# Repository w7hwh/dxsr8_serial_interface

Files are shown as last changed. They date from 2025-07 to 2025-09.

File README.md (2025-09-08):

# DX-SR8 Serial Interface

## Introduction

Since I have a DX-SR8 and a few Raspberry Pi Picos sitting around I decided to try building an interface based on a Raspberry Pi Pico 2. If nothing else the project will force me to become more familiar with MicroPython.

Back in 2013 AJ9BM did an analysis of the communication between the DX-SR8's chassis and its front panel. He found out a great deal about the protocol and built working prototypes but he eventually abandoned the project. More about his work is in [aj9bm.md](./aj9bm.md).
 
The micropython didn't work so well for me so I've switched to programming in C to run under freeRTOS. This was picked because of the same reason many things are decided, I have experience with both C and freeRTOS. :^) Initially I'm using a "Blue Pill" board with a cpu labeled STM32F103CBT6 . The ST-INFO utility says it has 256k flash and 64k of ram instead of the lower amounts that chip is supposed to have. 

---

## Planned stages are:

- [x] Micropython firmware to continue analyzing the protocol using a breadboarded RPi Pico 2. Essentially use the Pico as a double channel usb-serial adapter with some analysis/decoding capability. This includes converting the original python2 to python3.

- [ ] Firmware to actually control the radio. Currently planned to be in C running under freeRTOS.

- [ ] Design a board.

- [ ] Add capability to send CAT commands to control the rig.

- [ ] Add capability to send/receive audio?

---

## Contents:

- aj9bm_code/ -- The original python analysis code AJ9BM wrote back in 2013.
- board/ -- Board design files
- documentation/ -- Documenting the protocol between radio and head.
- firmware_c/ -- My code to run in C on a STM32 cpu. (currently a STM32F103 based 'Blue Pill' board.)
- firmware_python/ -- My code to run in MicroPython on a Raspberry Pi Pico 2. This has been abandoned in favor of the C version.
- images/ -- Images

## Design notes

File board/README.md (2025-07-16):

# DXSR8 Serial Interface Design Files

## GPIO Usage

- GP0  
- GP1  
- GP2  
- GP3  
- GP4	UART1-TX serial send to chassis
- GP5	UART1-RX serial receive from head
- GP6  
- GP7  
- GP8  
- GP9  
- GP10  
- GP11  
- GP12	UART0-TX serial send to head
- GP13	UART0-RX serial receive from chassis
- GP14  
- GP15  
- GP16	I2C0-SDA for SH1106 based display
- GP17	I2C0-SCL for SH1106 based display
- GP18  
- GP19  
- GP20  
- GP21  
- GP22  GP22-RELAY-CTL
- GP23  (wireless module) OP wireless power on signal
- GP24  (wireless module) OP/IP SPI data/IRQ
- GP25  (wireless module) OP SPI CS, when high also enable GP29 to read VSYS
- GP26	ADC0 monitor power from chassis
- GP27  ADC1 monitor power from USB
- GP28  
- GP29  (wireless module) OP/IP SPI CLK/ADC3 mode read VSYS/3
- WL-GPOI0  (wireless module) OP to LED
- WL-GPOI1  (wireless module) OP controls SMPS power save
- WL-GPOI2  (wireless module) IP high if VBUS present

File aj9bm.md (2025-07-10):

# AJ9BM's DX-SR8 Serial Interface

Back in 2013 AJ9BM did an analysis of the communication between the DX-SR8's chassis and its front panel. He found out a great deal about the protocol and built working prototypes but he eventually abandoned the project.
 
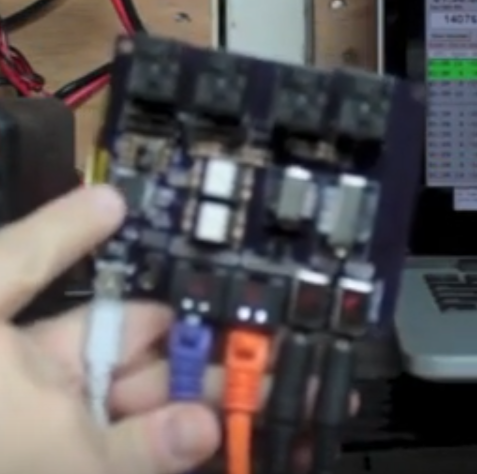
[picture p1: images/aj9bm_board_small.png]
aj9bm's board


Before he did he released the python analysis code that's in my /aj9bm_code directory [on Github](https://github.com/jbm9/dxsr8_serial).

He also posted three videos about the project on YouTube. Videos [showing the analysis code running](https://www.youtube.com/watch?v=cRo2k7FbKFA), [a prototype board controlling the rig](https://www.youtube.com/watch?v=0eBNIf6Rozc), and [one of a more finished prototype board controlling the rig](https://www.youtube.com/watch?v=aqtLbdCvwj8).

Unfortunately at that point he abandoned the project and never released the board design or the final code.

He added this to the captions on his videos:

> "UPDATE: I did not produce these for sale, and don't anticipate doing so.  There are enough kludges involved in getting this going that it's not worth sharing the project to other people, and (to be blunt) I would strongly recommend simply buying a better rig if you want to do computer control.  This is a great cheap 100W radio, but it's fairly dead-end in terms of third party support.  It doesn't even work properly with the autotuner you see in the video, for whatever reason."

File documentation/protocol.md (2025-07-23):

# DX-SR8 Head/Chassis Protocol

TODO:

- add examples and explainations for head to chassis part.

- document the chassis to head part.

---

## Introduction

The DXSR8's control head is connected to the chassis by a standard ethernet type cable with RJ45 connectors. It's not ethernet but it uses the same cable.

They communicate via two TTL level (5v) serial lines at 38400 8N1. They should not be directly connected to a 3.3v processor.

Most of the protocol was figured out by [AJ9BM](../aj9bm.md) back in 2013. He didn't produce documentation but it's in the python analysis code he released.

---

## Packets sent at powerup

b'AL~READY\r\n'

b'SWDA0000000081718AA1800100\r\n'

b'SWDV81728AA10100\r\n'

---

## Packets sent head to chassis

### AL~READY

b'AL~READY\r\n'

### SWDV

Contains rit, ifshift, squelch, and volume.

This is the most common packet because the values of these knobs jitter a little bit. These four are potentiometers and are read by ADCs (analog to digital converters). You get this even if you aren't touching the controls. They vary plus or minus one or two.

### SWDR

Contains the direction of rotation of the frequency dial

### SWDA

Related to the frequency dial? We get this packet when we spin the dial rapidly.

### SWDS

Contains the switches on the front panel excluding the power switch.
    
---

## Packets sent chassis to head

### AL~READY

b'AL~READY\r\n'

### LCSA

This contains bits controlling the LCD segments, LEDs, and display backlight. It seems to be the only thing the radio chassis transmits other than the initial ready message. It's sent continuously.

Details coming soon.

---

## Images of Display, Keys, and Head Schematic

Click for larger version.

Display

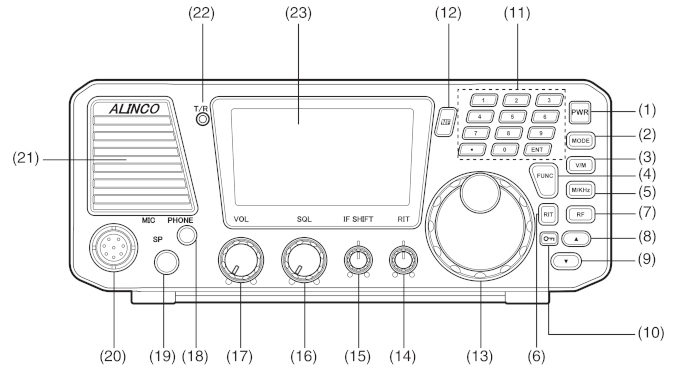
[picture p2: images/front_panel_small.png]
Front Panel


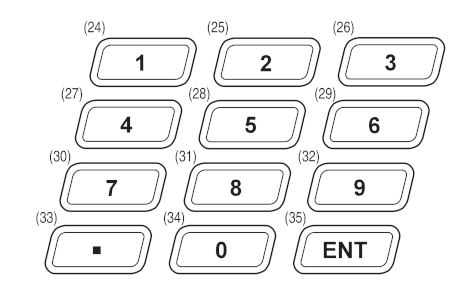
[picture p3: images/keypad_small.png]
Keypad


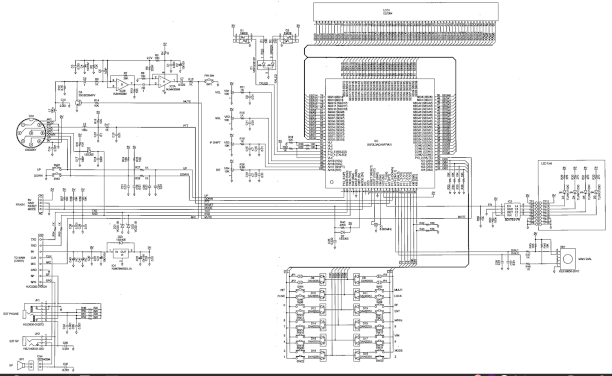
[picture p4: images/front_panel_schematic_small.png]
Front Panel Schematic


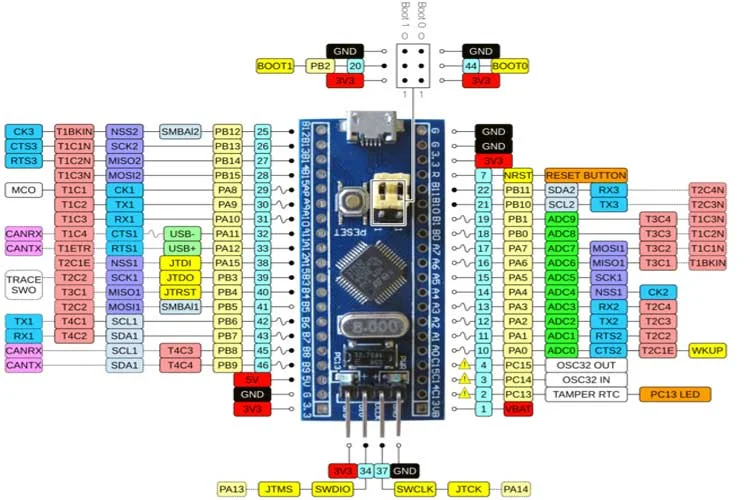
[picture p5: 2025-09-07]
documentation/STM32F103C8T6-Blue-Pill-pinout-diagram.webp

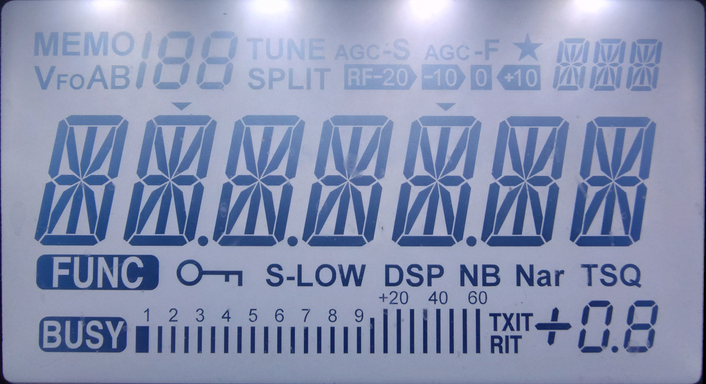
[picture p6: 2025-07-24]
images/display_all_segments_on.jpg

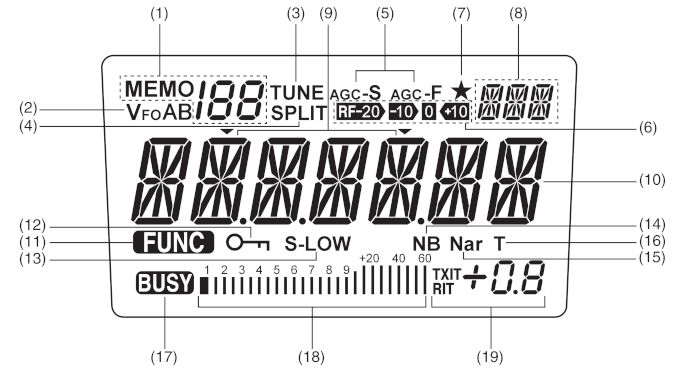
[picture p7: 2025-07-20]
images/display_small.png

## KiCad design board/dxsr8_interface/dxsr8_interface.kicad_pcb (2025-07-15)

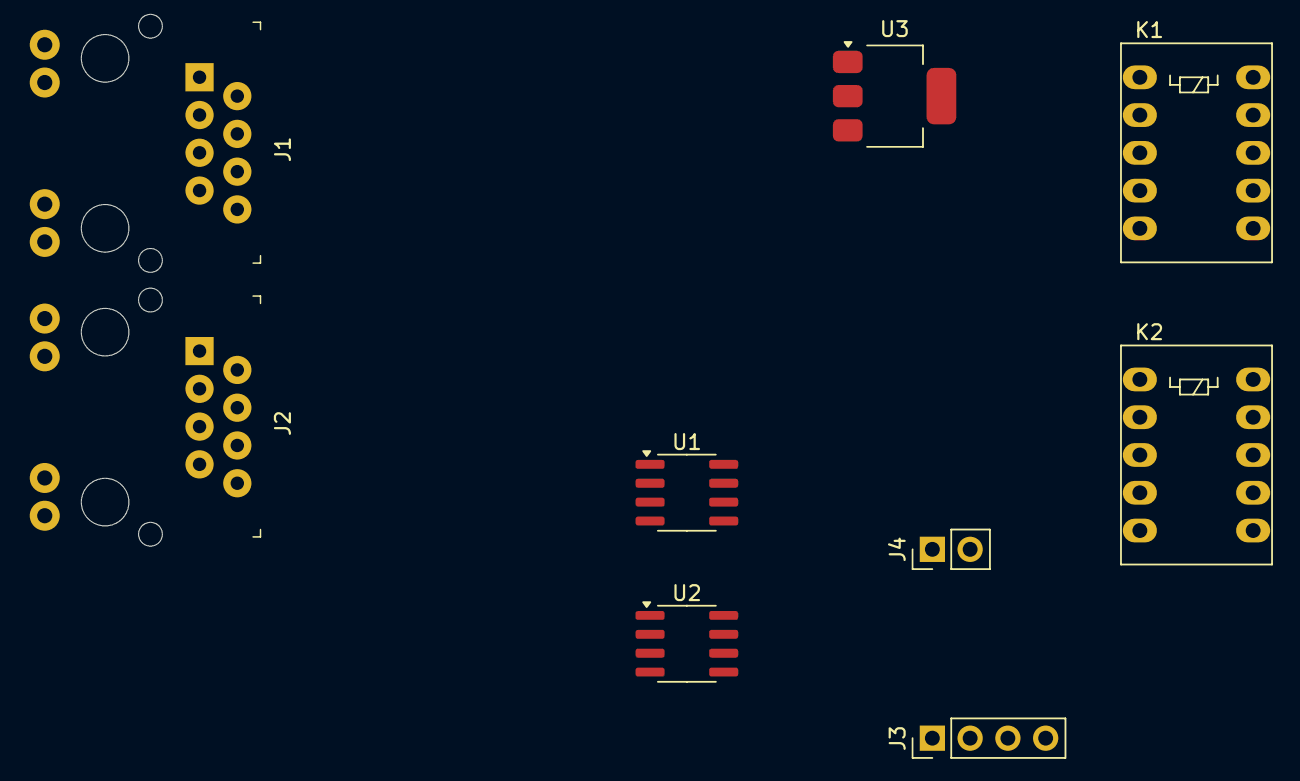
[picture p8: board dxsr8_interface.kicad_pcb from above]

Board: 2 copper layers, 9 parts (0 on the bottom side), 9 nets, no tracks yet.

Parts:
J1, J2: RJ45; Ethernet_Jack_ARJC02-111008B
J3: PinHeader_1x04_P2.54mm_Vertical
J4: NP; PinHeader_1x02_P2.54mm_Vertical
K1, K2: Relay_DPDT; Relay_DPDT_FRT5
U1, U2: ADuM1201AR; SOIC-8_3.9x4.9mm_P1.27mm
U3: AMS1117-5.0; SOT-223-3_TabPin2

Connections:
+8V: J1.3, J2.3, U3.3 (VI)
/CLN: J1.4, J2.4
/CRXD: J1.2, J2.2
/CTXD: J1.1, J2.1
/MIC: J1.5, J2.5
/SP: J1.7, J2.7
/SPG: J1.8, J2.8
GND: J3.1, J4.1
GND1: J1.6, J1.9, J2.6, J2.9, J4.2, U3.1 (GND)

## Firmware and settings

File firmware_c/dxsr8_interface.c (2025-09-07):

/* dxsr8_interface.c
 *
 * Last edit:	20250906 1115 hrs by hwh
 *
 * Edit history:
 *
 * TODO:
 *	read/write usb
 *	read/write head
 *	read/write chassis
 *	decode head
 *	decode chassis
 *	encode head to chassis
 *	encode chassis to head
 *	respond to cat commands from usb
 *
 *
 * Port usage:
 *		PA2		TX2		to head
 *		PA3		RX2		from head
 *		PA11	USBDM	usb to host
 *		PA12	USBDP	usb to host
 *		PA13	SWDIO	debug
 *		PA14	SWCLK	debug
 *
 *		PB10	TX3		to chassis
 *		PB11	RX3		from chassis
 *
 *		PC13	LED		on board led
 *		PC14	OSC32	rtc crystal
 *		PC15	OSC32	rtc crystal
 *
 */
#include <stdlib.h>
#include <string.h>
#include <stdbool.h>
#include <ctype.h>

//#include <libopencm3/cm3/cortex.h>
//#include <libopencm3/cm3/scb.h>
#include <libopencm3/stm32/rcc.h>
#include <libopencm3/stm32/gpio.h>
//#include <libopencm3/cm3/scb.h>
//#include <libopencm3/stm32/exti.h>
//#include <libopencm3/stm32/adc.h>
//#include <libopencm3/stm32/timer.h>
//#include <libopencm3/stm32/dma.h>
//#include <libopencm3/stm32/rtc.h>
//#include <libopencm3/stm32/f1/bkp.h>
//#include <libopencm3/stm32/f1/nvic.h>

//#include "mcuio.h"
//#include "miniprintf.h"

#include "FreeRTOS.h"
#include "task.h"
#include "queue.h"

#include "cdcacm.h"

/*
 * Monitor task:
 */
static void
monitor_task(void *arg __attribute((unused))) {

	for (;;) {
		//monitor();
		gpio_toggle(GPIOC,GPIO13);
		vTaskDelay(500);
	}
}

/*
 * Main program: Device initialization etc.
 */
int
main(void) {

	rcc_clock_setup_pll(&rcc_hse_configs[RCC_CLOCK_HSE8_72MHZ]);

	setup_usb();

	rcc_periph_clock_enable(RCC_GPIOC);
	gpio_set_mode(GPIOC,GPIO_MODE_OUTPUT_50_MHZ,GPIO_CNF_OUTPUT_PUSHPULL,GPIO13);

	xTaskCreate(monitor_task,"monitor",350,NULL,1,NULL);

	gpio_clear(GPIOC,GPIO13);

	vTaskStartScheduler();

	for (;;);
	return 0;
}

/* End main.c */

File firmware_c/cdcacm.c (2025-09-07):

/*
 * This file is part of the libopencm3 project.
 *
 * Copyright (C) 2010 Gareth McMullin <gareth@blacksphere.co.nz>
 *
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
 * You should have received a copy of the GNU Lesser General Public License
 * along with this library.  If not, see <http://www.gnu.org/licenses/>.
 */

#include <stdio.h>
#include <stdlib.h>
#include <libopencm3/stm32/rcc.h>
#include <libopencm3/stm32/gpio.h>
#include <libopencm3/usb/usbd.h>
#include <libopencm3/usb/cdc.h>

#include "FreeRTOS.h"
#include "task.h"
#include "queue.h"

#include "cdcacm.h"
#include "unique_id.h"
#include "stm32_uidhash.h"

static QueueHandle_t usb_rxq, usb_txq;

static const struct usb_device_descriptor dev = {
	.bLength = USB_DT_DEVICE_SIZE,
	.bDescriptorType = USB_DT_DEVICE,
	.bcdUSB = 0x0200,
	.bDeviceClass = USB_CLASS_CDC,
	.bDeviceSubClass = 0,
	.bDeviceProtocol = 0,
	.bMaxPacketSize0 = 64,
	.idVendor = 0x0483,
	.idProduct = 0x5740,
	.bcdDevice = 0x0200,
	.iManufacturer = 1,
	.iProduct = 2,
	.iSerialNumber = 3,
	.bNumConfigurations = 1,
};

/*
 * This notification endpoint isn't implemented. According to CDC spec its
 * optional, but its absence causes a NULL pointer dereference in Linux
 * cdc_acm driver.
 */
static const struct usb_endpoint_descriptor comm_endp[] = {{
	.bLength = USB_DT_ENDPOINT_SIZE,
	.bDescriptorType = USB_DT_ENDPOINT,
	.bEndpointAddress = 0x83,
	.bmAttributes = USB_ENDPOINT_ATTR_INTERRUPT,
	.wMaxPacketSize = 16,
	.bInterval = 255,
}};

static const struct usb_endpoint_descriptor data_endp[] = {{
	.bLength = USB_DT_ENDPOINT_SIZE,
	.bDescriptorType = USB_DT_ENDPOINT,
	.bEndpointAddress = 0x01,
	.bmAttributes = USB_ENDPOINT_ATTR_BULK,
	.wMaxPacketSize = 64,
	.bInterval = 1,
}, {
	.bLength = USB_DT_ENDPOINT_SIZE,
	.bDescriptorType = USB_DT_ENDPOINT,
	.bEndpointAddress = 0x82,
	.bmAttributes = USB_ENDPOINT_ATTR_BULK,
	.wMaxPacketSize = 64,
	.bInterval = 1,
}};

static const struct {
	struct usb_cdc_header_descriptor header;
	struct usb_cdc_call_management_descriptor call_mgmt;
	struct usb_cdc_acm_descriptor acm;
	struct usb_cdc_union_descriptor cdc_union;
} __attribute__((packed)) cdcacm_functional_descriptors = {
	.header = {
		.bFunctionLength = sizeof(struct usb_cdc_header_descriptor),
		.bDescriptorType = CS_INTERFACE,
		.bDescriptorSubtype = USB_CDC_TYPE_HEADER,
		.bcdCDC = 0x0110,
	},
	.call_mgmt = {
		.bFunctionLength = 
			sizeof(struct usb_cdc_call_management_descriptor),
		.bDescriptorType = CS_INTERFACE,
		.bDescriptorSubtype = USB_CDC_TYPE_CALL_MANAGEMENT,
		.bmCapabilities = 0,
		.bDataInterface = 1,
	},
	.acm = {
		.bFunctionLength = sizeof(struct usb_cdc_acm_descriptor),
		.bDescriptorType = CS_INTERFACE,
		.bDescriptorSubtype = USB_CDC_TYPE_ACM,
		.bmCapabilities = 0,
	},
	.cdc_union = {
		.bFunctionLength = sizeof(struct usb_cdc_union_descriptor),
		.bDescriptorType = CS_INTERFACE,
		.bDescriptorSubtype = USB_CDC_TYPE_UNION,
		.bControlInterface = 0,
		.bSubordinateInterface0 = 1, 
	 }
};

static const struct usb_interface_descriptor comm_iface[] = {{
	.bLength = USB_DT_INTERFACE_SIZE,
	.bDescriptorType = USB_DT_INTERFACE,
	.bInterfaceNumber = 0,
	.bAlternateSetting = 0,
	.bNumEndpoints = 1,
	.bInterfaceClass = USB_CLASS_CDC,
	.bInterfaceSubClass = USB_CDC_SUBCLASS_ACM,
	.bInterfaceProtocol = USB_CDC_PROTOCOL_AT,
	.iInterface = 0,

	.endpoint = comm_endp,

	.extra = &cdcacm_functional_descriptors,
	.extralen = sizeof(cdcacm_functional_descriptors)
}};

static const struct usb_interface_descriptor data_iface[] = {{
	.bLength = USB_DT_INTERFACE_SIZE,
	.bDescriptorType = USB_DT_INTERFACE,
	.bInterfaceNumber = 1,
	.bAlternateSetting = 0,
	.bNumEndpoints = 2,
	.bInterfaceClass = USB_CLASS_DATA,
	.bInterfaceSubClass = 0,
	.bInterfaceProtocol = 0,
	.iInterface = 0,

	.endpoint = data_endp,
}};

static const struct usb_interface ifaces[] = {{
	.num_altsetting = 1,
	.altsetting = comm_iface,
}, {
	.num_altsetting = 1,
	.altsetting = data_iface,
}};

static const struct usb_config_descriptor config = {
	.bLength = USB_DT_CONFIGURATION_SIZE,
	.bDescriptorType = USB_DT_CONFIGURATION,
	.wTotalLength = 0,
	.bNumInterfaces = 2,
	.bConfigurationValue = 1,
	.iConfiguration = 0,
	.bmAttributes = 0x80,
	.bMaxPower = 0x32,

	.interface = ifaces,
};

static const char *usb_strings[] = {
	"Amateur Radio W7HWH",
	"DXSR8 Interface",
	"1",
};

/* Buffer to be used for control requests. */
uint8_t usbd_control_buffer[128];

static enum usbd_request_return_codes cdcacm_control_request(usbd_device *usbd_dev, struct usb_setup_data *req, uint8_t **buf,
		uint16_t *len, void (**complete)(usbd_device *usbd_dev, struct usb_setup_data *req))
{
	(void)complete;
	(void)buf;
	(void)usbd_dev;

	switch(req->bRequest) {
	case USB_CDC_REQ_SET_CONTROL_LINE_STATE: {
		/*
		 * This Linux cdc_acm driver requires this to be implemented
		 * even though it's optional in the CDC spec, and we don't
		 * advertise it in the ACM functional descriptor.
		 */
		char local_buf[10];
		struct usb_cdc_notification *notif = (void *)local_buf;

		/* We echo signals back to host as notification. */
		notif->bmRequestType = 0xA1;
		notif->bNotification = USB_CDC_NOTIFY_SERIAL_STATE;
		notif->wValue = 0;
		notif->wIndex = 0;
		notif->wLength = 2;
		local_buf[8] = req->wValue & 3;
		local_buf[9] = 0;
		// usbd_ep_write_packet(0x83, buf, 10);
		return USBD_REQ_HANDLED;
		}
	case USB_CDC_REQ_SET_LINE_CODING: 
		if(*len < sizeof(struct usb_cdc_line_coding))
			return USBD_REQ_NOTSUPP;

		return USBD_REQ_HANDLED;
	}
	return USBD_REQ_NOTSUPP;
}

static void cdcacm_data_rx_cb(usbd_device *usbd_dev, uint8_t ep)
{
	(void)ep;

	char buf[64];
	int len = usbd_ep_read_packet(usbd_dev, 0x01, buf, 64);

	if (len) {
		usbd_ep_write_packet(usbd_dev, 0x82, buf, len);
	}
}

static void cdcacm_set_config(usbd_device *usbd_dev, uint16_t wValue)
{
	(void)wValue;

	usbd_ep_setup(usbd_dev, 0x01, USB_ENDPOINT_ATTR_BULK, 64, cdcacm_data_rx_cb);
	usbd_ep_setup(usbd_dev, 0x82, USB_ENDPOINT_ATTR_BULK, 64, NULL);
	usbd_ep_setup(usbd_dev, 0x83, USB_ENDPOINT_ATTR_INTERRUPT, 16, NULL);

	usbd_register_control_callback(
				usbd_dev,
				USB_REQ_TYPE_CLASS | USB_REQ_TYPE_INTERFACE,
				USB_REQ_TYPE_TYPE | USB_REQ_TYPE_RECIPIENT,
				cdcacm_control_request);
}

/* 
 * USB task:
 */
static void
usb_task(void *usbd_dev) {

	for (;;) {
		usbd_poll((usbd_device *)usbd_dev);
		//vTaskDelay(50);
	}
}
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

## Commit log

2025-07-13 switch to ADM1201 isolators, add regulator for them
    [dxsr8_interface.kicad_sch]
2025-07-15 work on board design
    [dxsr8_interface.kicad_pcb, dxsr8_interface.kicad_sch]
2025-07-16 add relay control to gpio list
2025-07-18 decided wifi is not necessare, switch from pico 2w to pico 2
2025-08-25 last update of the python version as I switch to C
2025-08-25 update readme for switch to C and freeRTOS.
2025-09-07 add pinout diagram of blue pill board

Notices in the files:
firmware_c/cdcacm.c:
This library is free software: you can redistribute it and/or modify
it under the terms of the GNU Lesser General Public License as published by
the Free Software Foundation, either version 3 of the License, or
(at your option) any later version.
